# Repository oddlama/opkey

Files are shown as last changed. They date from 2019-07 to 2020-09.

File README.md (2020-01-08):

# OpKey

Optical Key Sensor and MIDI controller for acoustic pianos, because why not.

## Hardware

All hardware pcbs are designed in KiCad. You will find them in the `hardware/` folder.
Do not forget to include the provided library for all components which are not found in the standard library.

* The controller board
* The sensor board (the normal 15 sensors veriant and one remainder for the low part of the keyboard)
  - 15 sensor variant is stacked 5 times
  - 13+2 sensors variant terminates the chain at the left end of the keyboard and adds auxiliary inputs for two pedal sensors
* A mini board for auxiliary sensors (pedals)

### Connection Diagram

```
                     LED strip
 o─o─o─o─o─o─o─o─o─o─o─o─o─o─o─o─o─o─o─o─o─o─o─o─o─o─o────╖
                                                          ║
  ╔═══ Soft Pedal (Una Corda)                             ║
  ║ ╔═ Damp Pedal (Sustain)                               ║
  ║ ║                                                     ║
┌─╨─╨──────────┐ ┌────────────┐     ┌────────────┐  ┌─────╨──────┐
│ 13+2 Sensors │ │ 15 Sensors │  …  │ 15 Sensors │  │ Controller │
│    Board 1   ╞═╡   Board 2  ╞/ … /╡   Board 6  ╞══╡ Controller ╞═ [+5V]
└──────────────┘ └────────────┘     └────────────┘  └────────────┘
```

### Issues

* 5V rail needs to be regulated
* Has filling both sides with copper been a good idea?
* SPI signal quality is crappy (cannot get above 4-5MHz, while ADC could do 20MHz and ESP32 could do 80MHz)
* The flat cables weren't my best idea... They proved to be a real pain in the ass.
  (Very unusual part, expensive and not available in correct lengths)
* All sensors are currently in line with each other, while the pivot points for black keys
  differs from the pivot point of white keys. This causes black keys to have a lot more travel at the
  sensor than white keys.
* We definitely need a way to properly calibrate all keys. The reflected amount of light
  varies, because of the wood texture of the keys, voltage drop from the length of all modules,
  and probably some other factors (mounting angle difference, factory deviation for IR LEDs and sensors...)
* The low-pass filter seems to work fine, but maybe it should be tested properly.
* Could a differentiator be used after the sensor to get more accurate and comparable velocity measurements? 
* The reference volatage at the ADCs could have been a mistake,
  because the sensor output voltage is not regulated.
* Some deterministic BLE transmission every .5 seconds causes sensor values to fluctuate by 2-3 bits. (Some kind of BLE heartbeat?)
  This could be either an induced current in the sensing line, or more likely a voltage drop caused by the TX module.
  Though indeed my antenna is exactly in line with the long side of the module, and therefore most of the traces on that PCB.
* The 3 zener diode package for USB line protection is upside down. (Wrong part pinout or footprint selected)
* We need USB midi out for low latency, and pure MIDI out for even better latency (don't forget optocouplers).
* Replace ESP32 by several proper processors (would allow full ADC utilization, see Software#Issues below for more)

## Software

The software for the ESP32 controller currently works like this:

Core 0 is responsible for BLE communication and LED visualization.
The BLE framework is the nimble, which is the recommended BLE framework according to Espressif.
Unfortunately, it really isn't a piece of cake.
See my issues [#4012](https://github.com/espressif/esp-idf/issues/4012)
and [#4328](https://github.com/espressif/esp-idf/issues/4328),
lets hope that there won't be any other issues.

Core 1 has been completely dedicated to this single FreeRTOS thread, to reduce scheduling
to the bare minimum. This allows it to be fully utilized for SPI communication and key state
calculation. While in theory the whole scheduling could be disabled by actually removing the
core from FreeRTOS initialization (via `start1.c`), this would also prevent us from using
`stdout` for UART communication. So I can't focus on this while the software is still heavily debugged.
Nontheless, this still gives us somewhat deterministic timings between sensor reads (good enough - down to some us).

SPI communication is polling, allowing us to process the previous sample while the
hardware SPI driver is busy with transactions for the next sample.

### Software summary

#### Core 0:

* Reads sensor's over SPI 
* Calculates key states
* Notifies other modules if key is pressed

#### Core 1:

* System threads (BLE driver, ...)
* Handles BLE communication
* Controls LED strip (calculates color and send's LED states)

### Issues

* Can the two SPI channels be used simultaneously?
* BLE midi has unpredictable latency.
* Recorded files seem to be missing the time code correction (probably an arecordmidi problem)
* Even though the two cores should be operating simultaneously, they are heavily influenced
  by each other (forced cache synchronization, fences in FreeRTOS code). e.g. TX for BLE on core 0
  causes core 1 to slow down, which is like the best thing ever for deterministic timing requirements!
  Admit it, you simply gotta love it.
* Separated hardware for each "process" would most likely eliminate most of these concerns.
  - One processor for each ADC (for SPI communication and key state calculation).
  - One processor to convert these signals to MIDI line
  - One processor for visualization
  - External BLE processor (nRF51 with [bluetoe](https://github.com/TorstenRobitzki/bluetoe))

Please don't judge the code layout too much, the ESP SDK really seems to hate good code.
Their giant pile of bloated cmake prevents you from using proper cmake (and forces you to use flat code layout).

## Images

Some images of the finished PCBs and the assembly process, as well as the BLE fluctuation
can be found [here](IMAGES.md)

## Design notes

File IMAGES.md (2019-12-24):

#### Other



#### Boards

 
 

#### Assembly

 
 


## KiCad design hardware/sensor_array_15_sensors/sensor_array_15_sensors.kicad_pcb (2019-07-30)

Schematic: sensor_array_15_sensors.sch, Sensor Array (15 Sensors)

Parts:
C1, C2, C3, C4, C5, C6, C7, C8, C9, C10, C11, C12, C13, C14, C15, C21, C23: 100nF; C_0805_2012Metric_Pad1.15x1.40mm_HandSolder
C16, C17, C18: 1µF; C_0603_1608Metric_Pad1.05x0.95mm_HandSolder
C19: 10µF; C_0603_1608Metric_Pad1.05x0.95mm_HandSolder
C20, C22: 10uF; CP_EIA-2012-15_AVX-P_Pad1.30x1.05mm_HandSolder
H1, H2, H3, H4, H5, H6: M2; MountingHole_2.2mm_M2_Pad_Via
J1, J2: Conn_01x17; Molex_200528-0170_1x17-1MP_P1.00mm_Horizontal
J3: Conn_01x04; PinHeader_1x04_P2.54mm_Horizontal
J4: Conn_01x04; Molex_200528-0040_1x04-1MP_P1.00mm_Horizontal
J5: Conn_01x03; PinHeader_1x03_P2.54mm_Horizontal
JP1, JP2, JP3, JP4, JP5, JP6: CS; SolderJumper-2_P1.3mm_Open_RoundedPad1.0x1.5mm
JP7, JP8, JP9, JP10, JP11, JP12: SDO; SolderJumper-2_P1.3mm_Open_RoundedPad1.0x1.5mm
R1, R2, R3, R13, R14: 47; R_0805_2012Metric_Pad1.15x1.40mm_HandSolder
R4, R5, R6, R7, R8, R9, R10, R11, R12, R15, R16, R17, R18, R19, R20: 10k; R_0805_2012Metric_Pad1.15x1.40mm_HandSolder
R21: 4k7; R_0805_2012Metric_Pad1.15x1.40mm_HandSolder
RV1, RV2, RV3, RV4, RV5: 100; Potentiometer_Bourns_TC33X_Vertical
U1, U2, U3, U4, U5, U6, U7, U8, U9, U10, U11, U12, U13, U14, U15: QRE1113; OnSemi_CASE100CY
U16: ADS7953; TSSOP-38_4.4x9.7mm_P0.5mm
U17: LM4040DBZ-2.5; SOT-23

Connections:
+3V3: C16.2, C20.1, C21.2, J1.16, J2.2, U16.36
+5V: C17.1, C18.1, C22.1, C23.2, J1.1, J1.17, J2.1, J2.17, J5.3, R1.2, R2.2, R3.2, R13.2, R14.2, R21.2, U1.3, U2.3, U3.3, U4.3, U5.3, U6.3, U7.3, U8.3, U9.3, U10.3, U11.3, U12.3, U13.3, U14.3, U15.3, U16.5, U16.29
/CH0: C15.1, R20.2, U15.4, U16.28
/CH1: C14.1, R19.2, U14.4, U16.27
/CH2: C13.1, R18.2, U13.4, U16.26
/CH3: C12.1, R17.2, U12.4, U16.25
/CH4: C11.1, R16.2, U11.4, U16.24
/CH5: C10.1, R15.2, U10.4, U16.23
/CH6: C9.1, R12.2, U9.4, U16.22
/CH7: C8.1, R11.2, U8.4, U16.21
/CH8: C7.1, R10.2, U7.4, U16.18
/CH9: C6.1, R9.2, U6.4, U16.17
/CH10: C5.1, R8.2, U5.4, U16.16
/CH11: C4.1, R7.2, U4.4, U16.15
/CH12: C3.1, R6.2, U3.4, U16.14
/CH13: C2.1, R5.2, U2.4, U16.13
/CH14: C1.1, R4.2, U1.4, U16.12
/CH15: J5.2, U16.11
CS: JP1.2 (B), JP2.2 (B), JP3.2 (B), JP4.2 (B), JP5.2 (B), JP6.2 (B), U16.31
CS0: J1.15, J2.3, JP1.1 (A)
CS1: J1.14, J2.4, JP2.1 (A)
CS2: J1.13, J2.5, JP3.1 (A)
CS3: J1.12, J2.6, JP4.1 (A)
CS4: J1.11, J2.7, JP5.1 (A)
CS5: J1.10, J2.8, JP6.1 (A)
GND: C1.2, C2.2, C3.2, C4.2, C5.2, C6.2, C7.2, C8.2, C9.2, C10.2, C11.2, C12.2, C13.2, C14.2, C15.2, C16.1, C17.2, C18.2, C19.2, C20.2, C21.1, C22.2, C23.1, H1.1, H2.1, H3.1, H4.1, H5.1, H6.1, J1.5, J1.9, J2.9, J2.13, J5.1, R4.1, R5.1, R6.1, R7.1, R8.1, R9.1, R10.1, R11.1, R12.1, R15.1, R16.1, R17.1, R18.1, R19.1, R20.1, U3.2 (K), U6.2 (K), U9.2 (K), U12.2 (K), U15.2 (K), U16.3, U16.6, U16.9, U16.10, U16.19, U16.20, U16.30, U16.35, U17.2 (A)
GPIO0: J3.4, J4.1, U16.37
GPIO1: J3.3, J4.2, U16.38
GPIO2: J3.2, J4.3, U16.1
GPIO3: J3.1, J4.4, U16.2
unnamed: C19.1, R21.1, U16.4, U17.1 (K)
unnamed: R1.1, RV1.1, RV1.2
unnamed: R2.1, RV2.1, RV2.2
unnamed: R3.1, RV3.1, RV3.2
unnamed: R13.1, RV4.1, RV4.2
unnamed: R14.1, RV5.1, RV5.2
unnamed: RV1.3, U1.1 (A)
unnamed: RV2.3, U4.1 (A)
unnamed: RV3.3, U7.1 (A)
unnamed: RV4.3, U10.1 (A)
unnamed: RV5.3, U13.1 (A)
unnamed: U1.2 (K), U2.1 (A)
unnamed: U2.2 (K), U3.1 (A)
unnamed: U4.2 (K), U5.1 (A)
unnamed: U5.2 (K), U6.1 (A)
unnamed: U7.2 (K), U8.1 (A)
unnamed: U8.2 (K), U9.1 (A)
unnamed: U10.2 (K), U11.1 (A)
unnamed: U11.2 (K), U12.1 (A)
unnamed: U13.2 (K), U14.1 (A)
unnamed: U14.2 (K), U15.1 (A)
unnamed: U16.7, U16.8
SCLK: JP11.2 (B), JP12.2 (B), U16.32
SCLK0: J1.6, J2.12, JP11.1 (A)
SCLK1: J1.2, J2.16, JP12.1 (A)
SDI: JP9.2 (B), JP10.2 (B), U16.33
SDI0: J1.7, J2.11, JP9.1 (A)
SDI1: J1.3, J2.15, JP10.1 (A)
SDO: JP7.2 (B), JP8.2 (B), U16.34
SDO0: J1.8, J2.10, JP7.1 (A)
SDO1: J1.4, J2.14, JP8.1 (A)

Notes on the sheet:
Sensor Array 1-9
Sensor Array 10-15
Power Flags
Mounting Holes
ADC
REFP resistance is 100k, so Iq is 25 µA. Rs = (Vs - Vr) / (Ir + Iq), settle for Ir + Iq = 500µA => R_S = 2.5V/500µA = 5k Round to E12 = 4k7
GPIO Header
SPI & Power Connectors
CS Line Select
Power Buffer
CH15 Header
SPI Line Select

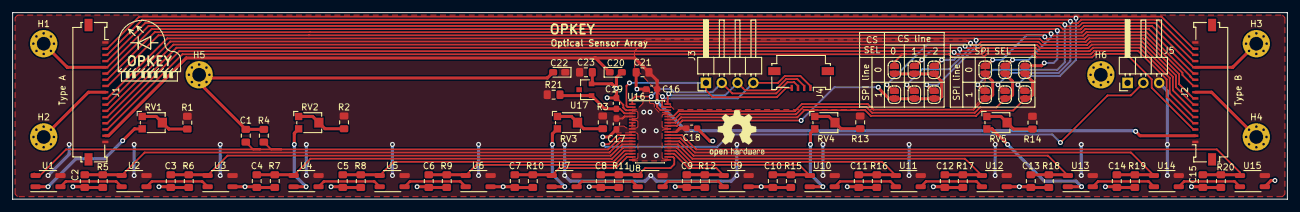
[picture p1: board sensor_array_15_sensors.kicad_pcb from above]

Board: 2 copper layers, 205.0 x 30.0 mm, 89 parts (0 on the bottom side), 61 nets.

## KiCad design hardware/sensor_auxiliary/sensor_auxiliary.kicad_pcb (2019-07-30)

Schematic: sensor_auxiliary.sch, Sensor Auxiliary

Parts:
C1, C3: 100nF; C_0805_2012Metric_Pad1.15x1.40mm_HandSolder
C2: 10uF; CP_EIA-2012-15_AVX-P_Pad1.30x1.05mm_HandSolder
H1, H2, H3, H4: M2; MountingHole_2.2mm_M2_Pad_Via
J1: Conn_01x04; Molex_200528-0040_1x04-1MP_P1.00mm_Horizontal
R1: 150; R_0805_2012Metric_Pad1.15x1.40mm_HandSolder
R2: 10k; R_0805_2012Metric_Pad1.15x1.40mm_HandSolder
RV1: 200; Potentiometer_Bourns_TC33X_Vertical
U1: QRE1113; OnSemi_CASE100CY

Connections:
+5V: C2.1, C3.2, J1.3, R1.1, U1.3
/SENSOR_AUX: C1.1, J1.1, R2.2, U1.4
GND: C1.2, C2.2, C3.1, H1.1, H2.1, H3.1, H4.1, J1.2, J1.4, R2.1, U1.2 (K)
unnamed: R1.2, RV1.2, RV1.3
unnamed: RV1.1, U1.1 (A)

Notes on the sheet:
Sensor
Power Flags
Power Buffer
Mounting Holes
Connector

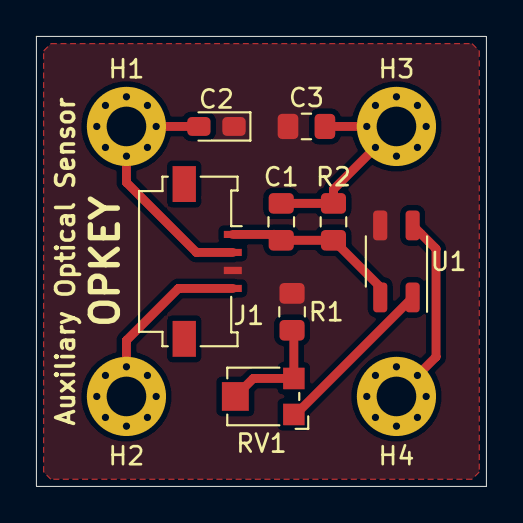
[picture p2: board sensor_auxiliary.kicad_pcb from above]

Board: 2 copper layers, 25.0 x 25.0 mm, 12 parts (0 on the bottom side), 5 nets.

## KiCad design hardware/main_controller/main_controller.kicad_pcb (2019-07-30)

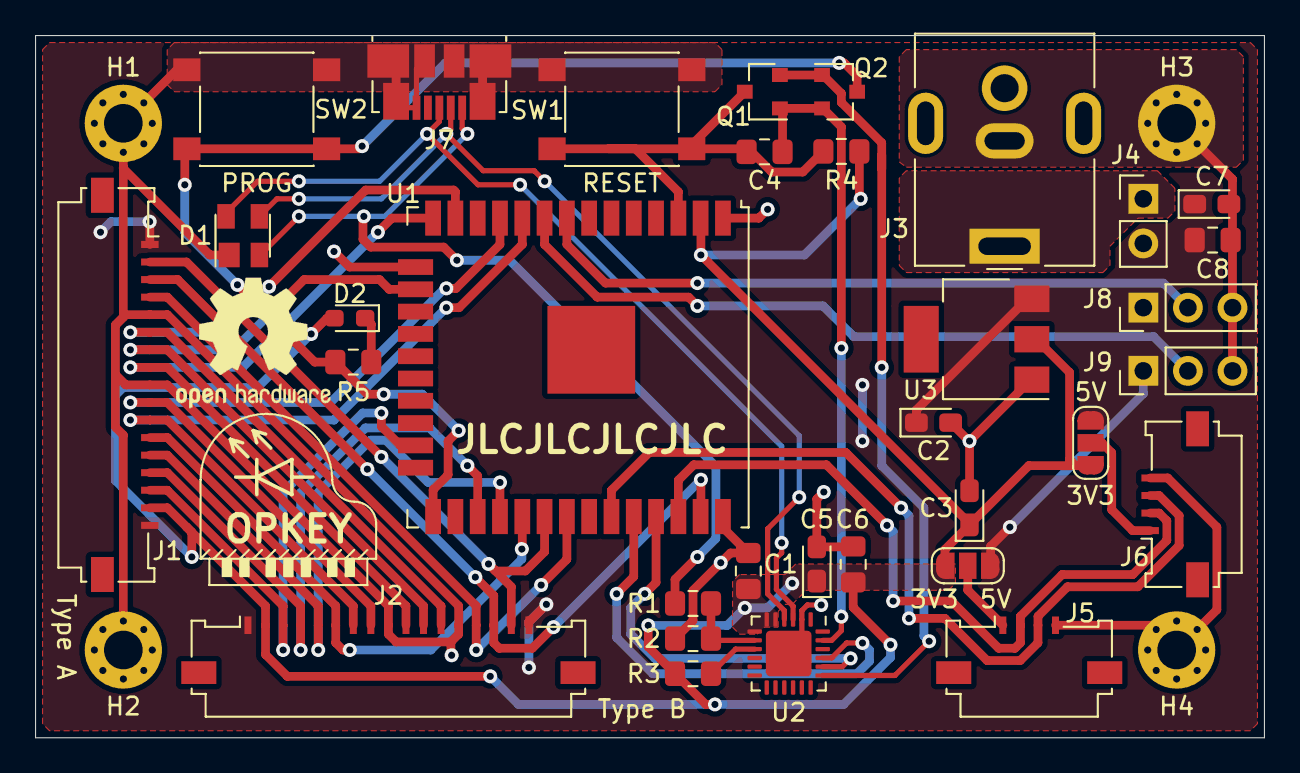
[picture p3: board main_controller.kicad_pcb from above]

Board: 2 copper layers, 70.0 x 40.0 mm, 37 parts (0 on the bottom side), 34 nets.

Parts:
C1, C4, C6, C8: 100nF; C_0805_2012Metric_Pad1.15x1.40mm_HandSolder
C2, C3: 47µF; CP_EIA-2012-15_AVX-P_Pad1.30x1.05mm_HandSolder
C5, C7: 10uF; CP_EIA-2012-15_AVX-P_Pad1.30x1.05mm_HandSolder
D1: SP0503BAHT; SOT-143
D2: LED_Blue_2V6_2mA; LED_0603_1608Metric_Pad1.05x0.95mm_HandSolder
H1, H2, H3, H4: M2; MountingHole_2.2mm_M2_Pad_Via
J1, J2: Conn_01x17; Molex_200528-0170_1x17-1MP_P1.00mm_Horizontal
J3: Barrel_Jack; BarrelJack_CUI_PJ-063AH_Horizontal
J4: Conn_01x02; PinHeader_1x02_P2.54mm_Vertical
J5, J6: Conn_01x04; Molex_200528-0040_1x04-1MP_P1.00mm_Horizontal
J7: USB_B_Micro; USB_Micro-B_Molex_47346-0001
J8, J9: Conn_01x03; PinHeader_1x03_P2.54mm_Vertical
JP1, JP2: SolderJumper_3_Open; SolderJumper-3_P1.3mm_Open_RoundedPad1.0x1.5mm_NumberLabels
Q1, Q2: 2N7002; SOT-23
R1: 24k; R_0805_2012Metric_Pad1.15x1.40mm_HandSolder
R2: 47k; R_0805_2012Metric_Pad1.15x1.40mm_HandSolder
R3: 4k7; R_0805_2012Metric_Pad1.15x1.40mm_HandSolder
R4: 10k; R_0805_2012Metric_Pad1.15x1.40mm_HandSolder
R5: 1k; R_0805_2012Metric_Pad1.15x1.40mm_HandSolder
SW1, SW2: SW_Push; SW_SPST_PTS645
U1: ESP32-WROOM-32U
U2: CP2104; QFN-24-1EP_4x4mm_P0.5mm_EP2.6x2.6mm
U3: LM1117-3.3; SOT-223

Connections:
+3V3: C1.1, C3.1, C5.1, C6.2, D2.2, J1.16, J2.2, JP1.3, JP2.3, R3.2, R4.2, U1.2, U2.5, U2.6, U2.7, U3.2
+5V: C2.1, C7.1, C8.2, J1.1, J1.17, J2.1, J2.17, J4.2, J8.1, J9.1, JP1.1, JP2.1, U3.3
CS0: J1.15, J2.3, U1.23
CS1: J1.14, J2.4, U1.27
CS2: J1.13, J2.5, U1.28
CS3: J1.12, J2.6, U1.29
CS4: J1.11, J2.7, U1.10
CS5: J1.10, J2.8, U1.11
DTR: C4.2, Q1.1, Q2.2, U2.23
EN: C4.1, Q1.3, R4.1, SW1.2, U1.3
GND: C1.2, C2.2, C3.2, C5.2, C6.1, C7.2, C8.1, D1.1, H1.1, H2.1, H3.1, H4.1, J1.5, J1.9, J2.9, J2.13, J3.2, J5.4, J6.4, J7.5, J7.6, J8.3, J9.3, R2.1, SW1.1, SW2.1, U1.1, U1.15, U1.38, U2.2, U2.25, U3.1
GPIO0: Q2.3, R5.1, SW2.2, U1.25
HSPI_MISO: J1.8, J2.10, U1.14
HSPI_MOSI: J1.7, J2.11, U1.16
HSPI_SCLK: J1.6, J2.12, U1.13
I2C_SCL: J5.2, J6.2, U1.36
I2C_SDA: J5.3, J6.3, U1.33
IO32: J8.2, U1.8
IO33: J9.2, U1.9
unnamed: D2.1, R5.2
unnamed: J3.1, J4.1
unnamed: J5.1, JP1.2
unnamed: J6.1, JP2.2
unnamed: R1.2, R2.2, U2.8
unnamed: R3.1, U2.9
RTS: Q1.2, Q2.1, U2.19
RXD0: U1.34, U2.21
SCLK1: J1.2, J2.16, U1.30
SDI1: J1.3, J2.15, U1.37
SDO1: J1.4, J2.14, U1.31
TXD0: U1.35, U2.20
USB_D+: D1.4, J7.3, U2.3
USB_D-: D1.3, J7.2, U2.4
USB_VBUS: D1.2, J7.1, R1.1

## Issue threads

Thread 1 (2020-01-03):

Hi

HAximand, 2020-01-03:
Hi I'm a rando wondering if this tech actually works and makes sense to install on a piano or if it is just a proof of concept. Github has no way to message a user so I'm trying this.

nyronium, 2020-01-05:
Yes, this tech does actually work, but keep in mind that this is a hobby project by myself. As you can see in the [images](https://github.com/nyronium/opkey/blob/master/IMAGES.md), I have successfully build it into my piano and am able to use it properly. Although, you should be aware that I have gathered a list of issues which I have found during the whole process. So there are definitely some things that could be improved.

I'm not sure which aspects you are referring to with "this tech", so let me summarize:
LED visualization is very responsive and flawless, but I am having some problems with MIDI recording (timing problems with Bluetooth LE), which I mainly attribute to the ESP32. Also the trigger and velocity detection still need some work to be perfect.

Closed 2020-01-16.

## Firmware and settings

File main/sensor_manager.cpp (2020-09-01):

#include "sensor_manager.h"
#include "calibration.h"
#include "application.h"

#include <driver/uart.h>


namespace opkey {

#ifdef ENABLE_SINGLE_SENSOR_MONITORING
auto WriteEnc = [](const auto* data, size_t count) {
	static std::array<uint16_t, 32> sendBuf{};
	static size_t sendBufCount = 0;

	sendBufCount = 0;
	auto begin = reinterpret_cast<const uint8_t*>(data);
	auto end = begin + count;
	for (auto d = begin; d != end; ++d) {
		sendBuf[sendBufCount] =
			((((*d & 0x0f) >> 0) + 'a') << 0) |
			((((*d & 0xf0) >> 4) + 'a') << 8);
		if (++sendBufCount == sendBuf.size()) {
			write(1, sendBuf.data(), sizeof(uint16_t) * sendBuf.size());
			sendBufCount = 0;
		}
	}

	if (sendBufCount > 0) {
		write(1, sendBuf.data(), sizeof(uint16_t) * sendBufCount);
	}
};
#endif

static SensorData tmpData{};


SensorManager::SensorManager(Application& application)
	: onTickConnection(application.GetOnTickSink().connect<&SensorManager::OnTick>(*this))
	, onModeChangeConnection(application.GetOnModeChangeSink().connect<&SensorManager::OnModeChange>(*this))
{ }


/**
 * Initialize the states with the given valid data
 */
void SensorManager::InitLogicStates(SensorData& newData) {
	OPKEY_PROFILE_FUNCTION();

	// Clean initial state
	logicStates = {};
	CalculateNextSensorState(newData);
}

void SensorManager::InitSingleSensorHistory() {
#ifdef ENABLE_SINGLE_SENSOR_MONITORING
	singleSensorHistory = {};
#endif
}

void SensorManager::CalculateNextSensorState(SensorData& newData) {
	OPKEY_PROFILE_FUNCTION();

	for (size_t i = 0; i < newData.size(); ++i) {
		CalculateNextSensorState(i, newData[i]);
	}
}

void SensorManager::CalculateNextSensorState(size_t rawIndex, double newData) {
	OPKEY_PROFILE_FUNCTION();

	// TODO static int64_t lastu = 0;
	// TODO static int xki = 0;
	// TODO if (rawIndex == 0) {
	// TODO 	++xki;
	// TODO 	auto now = esp_timer_get_time();
	// TODO 	auto diff = now - lastu;
	// TODO 	if (diff > 1000000) {
	// TODO 		fmt::print("tickrate per key: every {} us = {} tps\n", diff / xki, 1000000.0 * xki / diff);
	// TODO 		xki = 0;
	// TODO 		lastu = now;
	// TODO 	}
	// TODO }
	auto sensor = Sensor{config::GetSensorIndexFromRawIndex(rawIndex)};
	auto& state = logicStates[sensor];

	auto now = esp_timer_get_time();
	auto deltaTime = now - state.lastUpdateTime;
	state.lastUpdateTime = now;

#ifdef ENABLE_SINGLE_SENSOR_MONITORING
	state.delta = deltaTime;
	state.rawPos = static_cast<uint16_t>(newData * ads7953::values);
#endif

	// Store previous values
	auto prevPos = state.posHistory[state.currentHistoryIndex];
	auto prevVel = state.vel;

	//static int iii = 1;
	//if (iii % 100 == 0) {
	//	if (sensor.GetIndex() == 0x10u+0*12u || sensor.GetIndex() == 0x10u+0*12u+1u ||
	//		sensor.GetIndex() == 0x10u+1*12u || sensor.GetIndex() == 0x10u+1*12u+1u ||
	//		sensor.GetIndex() == 0x10u+2*12u || sensor.GetIndex() == 0x10u+2*12u+1u)
	//	{
	//		fmt::print("key[0x{:02x}, {:4s}] rawpos {}\n",
	//			sensor.GetIndex(),
	//			sensor.GetName(),
	//			newData);
	//	}
	//}
	//if (sensor.GetIndex() == 0u) {
	//	if (++iii == 1001) {
	//		iii = 1;
	//	}
	//}
	//// 1. Position is sqrt(data), because light intensity is 1/(distance^2)
	//// 2. Apply calibration
	//auto rawPos = sqrt(newData);
	//state.pos = calibration::calibrationData[sensor].Apply(rawPos);

	auto isWhiteKey = [](auto i) {
		switch (i / 12) {
			default:
			case 0:
			case 2:
			case 3:
			case 5:
			case 7:
			case 8:
			case 10:
				return true;
			case 1:
			case 4:
			case 6:
			case 9:
			case 11:
				return false;
		}
	};

	if (sensor.IsPedal()) {
		// TODO MISSING MEASUREMENT
		state.pos = sqrt(newData);
	} else if (isWhiteKey(sensor.GetKeyIndex())) {
		// White keys
		state.pos = -1.609864 + (19.9053 / 7.83965) * (1 - exp(-7.83965 * newData));
	} else {
		// Black keys
		state.pos = -0.7957951 + (9.450975 / 6.014812) * (1 - exp(-6.014812 * newData));
	}
	state.vel = (state.pos - prevPos) * (1000000.0 / deltaTime);

	// Save pos in history
	if (++state.currentHistoryIndex == state.posHistory.size()) {
		state.currentHistoryIndex = 0;
	}
	state.posHistory[state.currentHistoryIndex] = state.pos;
	state.deltaHistory[state.currentHistoryIndex] = deltaTime;

	if (sensor.IsPedal()) {
		state.changed = false;
		if (state.pressed) {
			if (state.pos < config::pedalReleaseThreshold) {
				state.changed = true;
				state.pressed = false;
				state.lastReleaseTime = now;
			}
		} else {
			if (state.pos >= config::pedalPressThreshold) {
				state.changed = true;
				state.pressed = true;
				state.lastPressTime = now;
			}
		}
	} else {
		state.changed = false;
		if (state.pressed) {
			if (state.pos < config::releasePositionAbsolute ||
					state.maxVelPos - state.pos > config::releasePositionThreshold * state.maxVelPos) {
				// The key was pressed and since then it has travelled up for
				// more than config::releasePositionThreshold (percentage) of the hit position.
				// Or it has fallen below the absolute release position.
				state.pressed = false;
				state.changed = true;
				state.lastReleaseTime = now;

				// Reset trigger variables
				state.maxVelTime = 0;
				state.maxVel = 0.0;
			}
		} else {
			// If the velocity is greater than the current max velocity
			if (state.vel > state.maxVel) {
				// Check for a valid velocity maximum
				if (config::IsValidVelocityMaximum(state.pos, state.vel)) {
					state.maxVelTime = now;
					state.maxVelPos = state.pos;
					state.maxVel = state.vel;

			 		state.pressed = true;
			 		state.changed = true;
			 		state.lastPressTime = state.maxVelTime;
			 		state.pressVelocity = CalculatePressVelocity(sensor, state);
				}
			}

			// // Check falling edge on velocity over config::triggerVelocityThreshold
			// if (prevVel > config::triggerVelocityThreshold &&
			// 		state.vel <= config::triggerVelocityThreshold) {
			// 	// Check if the trigger is still valid, and prevent triggers
			// 	// from key-release jittering
			// 	if (now - state.maxVelTime <= config::maxTriggerDelayUs &&
			// 			now - state.lastReleaseTime > config::minTriggerJitterDelayUs) {
			// 		// The position is past the high threshold
			// 		state.pressed = true;
			// 		state.changed = true;
			// 		state.lastPressTime = state.maxVelTime;
			// 		state.pressVelocity = CalculatePressVelocity(sensor, state);
			// 		//fmt::print("[2;37mkey[0x{:02x}, {:4s}] possible: pos {:7.2f} vel {:7.2f} EMApd{:7.2f} EMAvd {:7.2f}[m\n",
			// 		//	sensor.GetIndex(),
			// 		//	sensor.GetName(),
			// 		//	state.pos,
			// 		//	state.vel,
			// 		//	state.maxVelPosEma - state.maxVelPos,
			// 		//	state.maxVelEma - state.maxVel
			// 		//	);
			// 		//fmt::print("key[0x{:02x}, {:4s}] down: vel: {:7.2f}\n",
			// 		//	sensor.GetIndex(),
			// 		//	sensor.GetName(),
			// 		//	state.pressVelocity);
			// 	} else {
			// 		// The trigger has expired, reset max velocity state
			// 		state.maxVelTime = 0;
			// 		state.maxVel = 0.0;
			// 	}
			// }
		}
	}
}
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

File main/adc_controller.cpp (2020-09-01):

#include "adc_controller.h"
#include "application.h"
#include "ads7953.h"
#include "fmt.h"
#include "exception.h"


namespace opkey {


AdcController::AdcController() {
	OPKEY_PROFILE_FUNCTION();
	InitSpi();
}


void AdcController::InitSpi() {
	OPKEY_PROFILE_FUNCTION();
	esp::logi("Initializing SPI");

	hspi = SpiHost
		{ "hspi"
		, SpiHost::HostDevice::Hspi
		, config::hspi.pinSclk
		, config::hspi.pinMosi
		, config::hspi.pinMiso
		, DmaChannel::Dma1
		, 16
		};

	vspi = SpiHost
		{ "vspi"
		, SpiHost::HostDevice::Vspi
		, config::vspi.pinSclk
		, config::vspi.pinMosi
		, config::vspi.pinMiso
		, DmaChannel::Dma2
		, 16
		};

	adcs =
		{ hspi.AddDevice("adc0", config::hspi.pinCs[0], config::spiFrequency)
		, hspi.AddDevice("adc1", config::hspi.pinCs[1], config::spiFrequency)
		, hspi.AddDevice("adc2", config::hspi.pinCs[2], config::spiFrequency)
		, vspi.AddDevice("adc3", config::vspi.pinCs[0], config::spiFrequency)
		, vspi.AddDevice("adc4", config::vspi.pinCs[1], config::spiFrequency)
		//TODO temporarily disabled adc5   , vspi.AddDevice("adc5", config::vspi.pinCs[2], config::spiFrequency)
		};
}

void AdcController::SetAdcModeAuto() {
	OPKEY_PROFILE_FUNCTION();
	esp::logi("Set mode auto for ADCs");

	// Set mode to Auto1 with full input range
	auto setModeAuto1 = ads7953::SetModeAuto1{};
	setModeAuto1.programSettings = true;
	setModeAuto1.inputRange = ads7953::InputRange::Full;

	// Disable reading CH15
	auto programModeAuto1 = ads7953::ProgramModeAuto1{};
	programModeAuto1.channelMask = 0x7fff;

	auto tx = make_unique_dma<ads7953::Command>();
	auto rx = make_unique_dma<ads7953::Result>();
	for (auto& adc : adcs) {
		esp::logi("Set mode for '{}'", adc.GetName());
		ads7953::Transfer(adc, *rx, *tx, setModeAuto1);
		esp::logi("{:08b} {:08b}", rx->data[0], rx->data[1]);
		ads7953::Transfer(adc, *rx, *tx, programModeAuto1);
		esp::logi("{:08b} {:08b}", rx->data[0], rx->data[1]);
	}

	// Prepare several continueOperation transactions linked to rx and tx,
	// preinitialized with ads7953::ContinueOperation
	auto continueOperation = ads7953::ContinueOperation{};
	*continueOperationTx = continueOperation.ToCommand();

	for (int i = 0; i < config::numAdcs * config::numChannels; ++i) {
		continueOperationTransactions[i].flags     = 0;
		continueOperationTransactions[i].length    = continueOperationTx->data.size() * 8;
		continueOperationTransactions[i].tx_buffer = continueOperationTx->data.data();
		continueOperationTransactions[i].rxlength  = (*continueOperationRxs)[i].data.size() * 8;
		continueOperationTransactions[i].rx_buffer = (*continueOperationRxs)[i].data.data();
	}

	// Check that every adc is online and correctly
	// programmed by verifying a two full cycles
	for (auto& adc : adcs) {
		ads7953::Transfer(adc, *rx, *tx, continueOperation);
		int channel = rx->GetChannel();
		for (int i = 0; i < 2 * 15; ++i) {
			int expectedChannel = (channel + 1) % 15;
			ads7953::Transfer(adc, *rx, *tx, continueOperation);
			if (rx->GetChannel() != expectedChannel) {
				throw OpKeyException("ADC mode set error: '{}' returned invalid data"_format(adc.GetName()));
			}
			channel = expectedChannel;
		}
	}
}

void AdcController::SetAdcModeSingle() {
	OPKEY_PROFILE_FUNCTION();
	esp::logi("Set mode single channel auto for ADCs");

	// Set mode to Auto1 with full input range
	auto setModeAuto1 = ads7953::SetModeAuto1{};
	setModeAuto1.programSettings = true;
	setModeAuto1.inputRange = ads7953::InputRange::Full;

	// Disable reading all channels except the configured one
	int sChannel = config::GetRawIndexFromSensorIndex(mode_params::singleSensorMonitoringSensor.GetIndex()) % config::numChannels;
	auto programModeAuto1 = ads7953::ProgramModeAuto1{};
	programModeAuto1.channelMask = 1 << sChannel;

	auto tx = make_unique_dma<ads7953::Command>();
	auto rx = make_unique_dma<ads7953::Result>();
	for (int a = 0; a < config::numAdcs; ++a) {
		auto& adc = adcs[a];

		esp::logi("Set mode for '{}'", adc.GetName());
		ads7953::Transfer(adc, *rx, *tx, setModeAuto1);
		esp::logi("{:08b} {:08b}", rx->data[0], rx->data[1]);
		ads7953::Transfer(adc, *rx, *tx, programModeAuto1);
		esp::logi("{:08b} {:08b}", rx->data[0], rx->data[1]);
	}

	// Prepare several continueOperation transactions linked to rx and tx,
	// preinitialized with ads7953::ContinueOperation
	auto continueOperation = ads7953::ContinueOperation{};
	*continueOperationTx = continueOperation.ToCommand();

	for (int i = 0; i < config::numAdcs * config::numChannels; ++i) {
		continueOperationTransactions[i].flags     = 0;
		continueOperationTransactions[i].length    = continueOperationTx->data.size() * 8;
		continueOperationTransactions[i].tx_buffer = continueOperationTx->data.data();
		continueOperationTransactions[i].rxlength  = (*continueOperationRxs)[i].data.size() * 8;
		continueOperationTransactions[i].rx_buffer = (*continueOperationRxs)[i].data.data();
	}

	// Check that every adc is online and correctly
	// programmed by verifying a two full cycles
	for (auto& adc : adcs) {
		// Discard next operation, as it will be invalid (old conversion result and channel)
		ads7953::Transfer(adc, *rx, *tx, continueOperation);
		for (int i = 0; i < 2 * 15; ++i) {
			ads7953::Transfer(adc, *rx, *tx, continueOperation);
			if (rx->GetChannel() != sChannel) {
				throw OpKeyException("ADC mode set error: '{}' returned invalid data"_format(adc.GetName()));
			}
		}
	}
}


} // namespace opkey

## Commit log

2019-06-25 Added cpp_utils component from esp32-snippets
2019-06-25 Added current testing version
2019-06-25 Drastically improved sample rate by using DMA ready memory and batching transfers
2019-07-18 Added sensor schematics and pcbs
    [sensor_array_A_C.kicad_pcb, sensor_array_A_C.sch, sensor_array_Csharp_octave.kicad_pcb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]
2019-07-18 Renamed sensor_standalone to sensor_auxiliary
    [sensor_auxiliary.kicad_pcb, sensor_auxiliary.sch]
2019-07-21 Removed old sensor arrays, added new integrated 15 channel sensor array
    [sensor_array_15_sensors.kicad_pcb, sensor_array_15_sensors.sch, sensor_array_A_C.kicad_pcb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]
2019-07-23 Relayout for 2 SPI master lines, finished 14 and 15 sensor boards, finished auxiliary board
    [main_controller.kicad_pcb, main_controller.sch, sensor_array_13_sensors.kicad_pcb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]
2019-07-29 Created main controller. Prototypes finished.
    [main_controller.kicad_pcb, main_controller.sch, sensor_array_13_sensors.kicad_pcb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]
2019-07-29 Fixed OpKey logo (JLC dislikes negative angles), added gbr files
    [main_controller-B_Cu.gbr, main_controller-B_Mask.gbr, main_controller-B_Paste.gbr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]
2019-07-30 Final changes, regenerated gerber files
    [main_controller-B_Cu.gbr, main_controller-B_Mask.gbr, main_controller-B_Paste.gbr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]
2019-08-18 Implemented Rmt LedStrip controller
2019-08-18 Implemented interrupt profiling
2019-08-19 Implemented more events, begin optimizing ADC readout
2019-08-19 Adc sampling code finished, created temporary core-0 task for visualization
2019-08-19 Implemented sensor history and basic key state calculation.
2019-08-28 fixed namespace names, begin with ble templating
    [adc_controller.cpp, ads7953.h]
2019-09-06 Implemented global mode system, a calibration algorithm and visualization
2019-09-06 Implemented calibration data saving and restoring
2019-09-07 Added single sensor tracing mode and host application to convert the data to a plottable format
2019-09-09 Revert transmittion method for reliability
    [sensor_manager.cpp]
2019-09-10 Removed sensor history in favor of time and memory efficient logic states
2019-09-10 Added HSV converter, visualized new velocity
2019-09-20 Fixed recording keys with sharp symbol
    [sensor_manager.cpp, sensor_tensor.h]
2019-10-06 Increased ADC speed by processing data while polling for results, new key detection algorithm (WIP)
2019-10-09 Switchted single sensor mode to a continous plot with better audio correlation
2019-10-13 Fixed bias extraction bug caused by typo
    [sensor_manager.cpp]
2019-10-13 Removed debug prints
2019-10-24 Added timestamped midi messages; Added midi message recv sink; New small velocity detection model;
2019-10-27 Warm colors now; Also led input is now possible on ch0
2020-09-01 WIP: Disable adc 6 (connectivity issues), adjust color ramp
    [adc_controller.cpp, sensor_manager.cpp]
